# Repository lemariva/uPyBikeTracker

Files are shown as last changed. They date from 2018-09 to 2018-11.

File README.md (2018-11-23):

# uPyBikeTracker

## Main Hardware Components
| Part  | Description |  Qty |
|-:|-:|-:|
| [Wemos ESP32 Lora Board](https://www.banggood.com/2Pcs-Wemos-TTGO-LORA32-868915Mhz-ESP32-LoRa-OLED-0_96-Inch-Blue-Display-p-1239769.html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) | ESP32 + SSD1306 + SX1276 + CP2102| x1 |
| [GPS NEO7M](https://www.banggood.com/Ublox-NEO-7M-Flight-Controller-GPS-Module-Built-in-Data-Memory-p-973621.html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) / [GPS NEO6M](https://www.banggood.com/GY-NEO6MV2-New-NEO-6M-GPS-Module-NEO6MV2-with-Flight-Control-EEPROM-MWC-APM2_5-Large-Antenna-p-1348935.html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) | GPS Module| x1|
|[MPU9250/5](https://www.banggood.com/MPU-9250-GY-9250-9-Axis-Sensor-Module-I2C-SPI-Communication-Board-For-Arduino-p-1227241.html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)| IMU 10DOF Sensor| x1 |
|[IRLML2502](https://www.ebay.de/itm/20PCS-IRLML2502-ORIGINAL-MOSFET-N-CH-20V-4-2A-SOT-23-/162711066575) | MOSFETs | x4 | 
|[BME680](https://www.banggood.com/CJMCU-680-BME680-BOSCH-Temperature-And-Humidity-Pressure-Sensor-p-1268323.html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)| Atmospheric Pressure Sensor| x 1|
|[BQ27510-G3](http://www.ti.com/product/bq27510-g3/description) | Fuel Gauge |x1|
|[Lipo-Battery](https://www.banggood.com/ZOP-Power-3_7V-850mAh-1S-25C-Lipo-Battery-p-1013586.html?p=QW0903761303201409LG)| Battery| x1|
|[RTC Clock](https://www.conrad.de/de/ds1339u-33-tr-rtc-clockcalendar-i2c-interface-msop8-800202661.html)| Clock| x1 |
|[CR1220](https://www.conrad.de/de/knopfzellenhalter-1-cr-1216-cr-1220-horizontal-oberflaechenmontage-smd-l-x-b-x-h-1892-x-1207-x-318-mm-keystone-300-651317.html)| Battery Socket| x1 |
|[SIL Socket Row Strip PCB Connector](https://www.banggood.com/5-Pair-40-Pin-2_54mm-Male-Female-SIL-Socket-Row-Strip-PCB-Connector-p-953486.html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)| SIL Socket Row Strip PCB Connector | x1|
|[SMD Tact Push Buttons](https://www.banggood.com/100pcs-3-x-6-x-2_5mm-DC-12V-0_5A-SMD-Tact-Push-Button-Switch-p-1202259.html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)| Buttons| x4|
|[bq51013B](http://www.ti.com/product/BQ51013B/technicaldocuments)|  Highly Integrated Wireless Receiver Qi| x1|

## More Info
More info coming soon on [lemariva.com](https://lemariva.com).

## Revision
* 1.3v added wireless charging (not revised yet)
* 1.2v breakout boards integrated to the main board
* 1.1v added RTC Clock (DS1339)
* 1.0v initial commit

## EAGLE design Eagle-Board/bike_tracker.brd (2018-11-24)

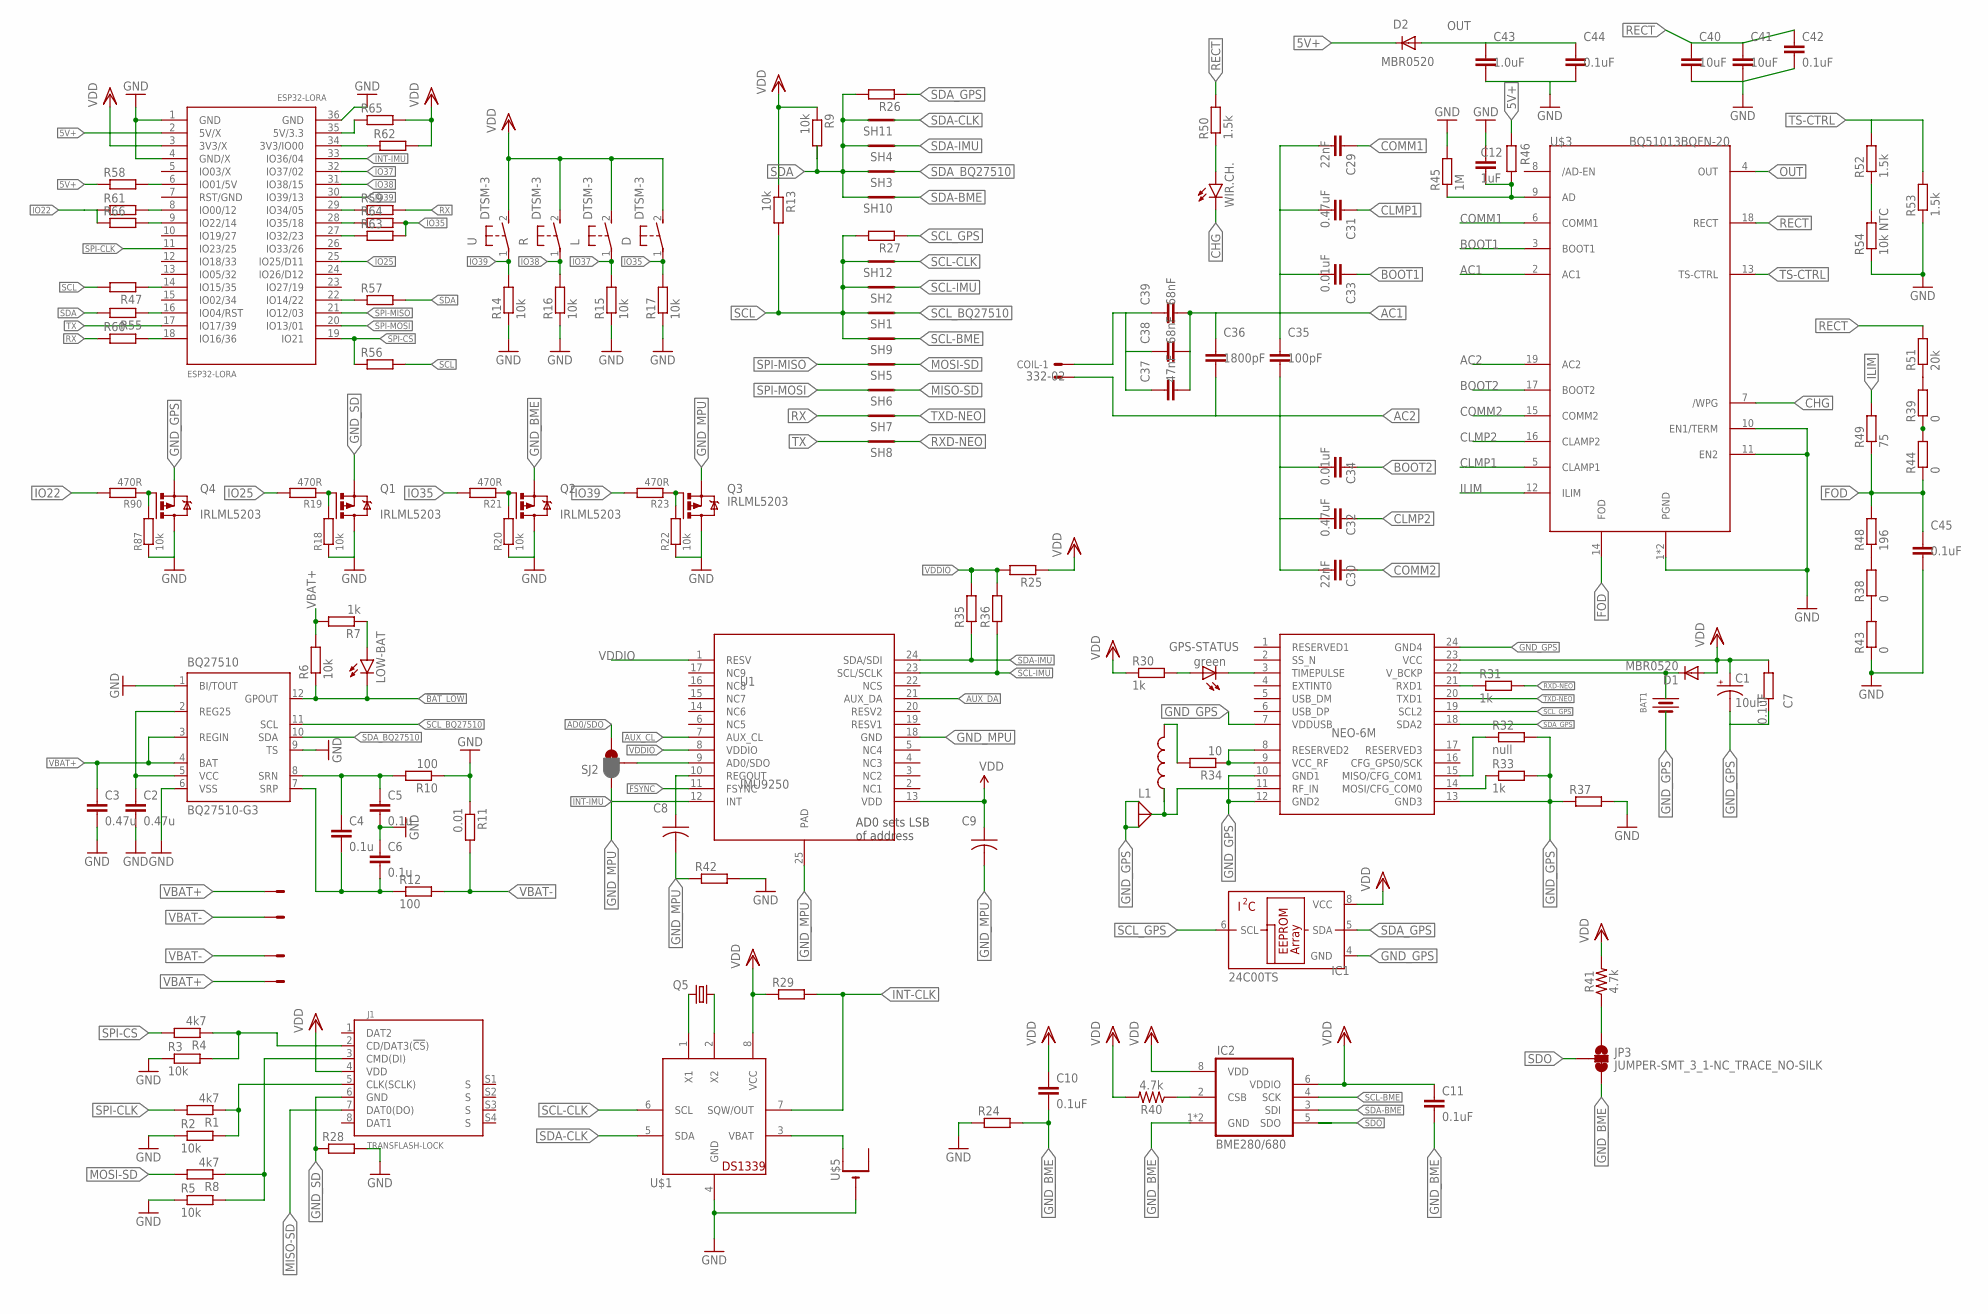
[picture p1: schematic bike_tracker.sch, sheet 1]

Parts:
BAT: 332-02
BAT1: XH414; TS414H
BAT-IN: 332-02
BQ27510: BQ27510-G3; DRZ
C1: 10uF; EIA3528
C2, C3: 0.47u; C0603
C4, C5, C6: 0.1u; C0603
C7: 0.1uF; R0603
C8, C9: 0.1uF; C0603K
C10, C11: 0.1uF; 0603
C12: 1uF; C0603
C29, C30: 22nF; C0603
C31, C32: 0.47uF; C0603
C33, C34: 0.01uF; C0603
C35: 100pF; C0603
C36: 1800pF; C0603
C37: 47nF; C0603
C38, C39: 68nF; C0603
C40, C41: 10uF; C0603
C42, C44, C45: 0.1uF; C0603
C43: 1.0uF; C0603
COIL: 332-02
D: DTSM-3
D1, D2: MBR0520; SOD123
ESP32-LORA: ESP32LORA; ESP32-LORA-TTGO
GPS-STATUS: green; 0805-LED
IC1: 24C00TS; TSSOP8
IC2: BME280/680; BME280
IPEX: ANT-UMCC; UMCC
J1: TRANSFLASH-LOCK; TRANSFLASH-LOCK-SOCK
JP3: JUMPER-SMT_3_1-NC_TRACE_NO-SILK; SMT-JUMPER_3_1-NC_TRACE_NO-SILK
L: DTSM-3
L1: INDUCTOR0603; 0603
LOW-BAT: LEDSML0805; SML0805
NEO-GPS: BLOX-NEO-6M; NE0-6M
Q1, Q2, Q3, Q4: IRLML5203; MICRO3
Q5: CRYSTALTC26H; TC26H
R: DTSM-3
R1, R4, R8: 4k7; R0603
R2, R3, R5, R6, R9, R13, R14, R15, R16, R17, R18, R20, R22, R87: 10k; R0603
R7, R30, R31, R33: 1k; R0603
R10, R12: 100; R0603
R11: 0.01; R0603
R19, R21, R23, R90: 470R; R0603
R24, R25, R26, R27, R28, R37, R42, R46, R47, R55, R56, R57, R58, R59, R60, R61, R62, R63, R64, R65, R66: R-EU_R0201; R0201
R29: R-EU_R0603; R0603
R32: null; R0603
R34: 10; R0603
R35, R36: 10K; R0603
R38, R39, R43, R44: 0; R0603
R40, R41: 4.7k; 0603
R45: 1M; R0603
R48: 196; R0603
R49: 75; R0603
R50, R52, R53: 1.5k; R0603
R51: 20k; R0603
R54: 10k NTC; R0603
SH1, SH2, SH3, SH4, SH5, SH6, SH7, SH8, SH9, SH10, SH11, SH12: SHORT; SHORT_TOP-20
SJ2: JUMPER_PAD-3-1&2_NC_BY_PASTE; PAD-HUMPER-3-1&2_NC_BY_PASTE_YES_SILK_FULL_BOX
U: DTSM-3
U1: IMU9250; LEAD-QFN24
U$1: DS1339; SOPM08
U$3: BQ51013BQFN-20; R-PVQFN-N20
U$5: CR1220SMT; CR1220-SMD
WIR.CH.: LEDSML0805; SML0805

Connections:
5V+: D2.C, ESP32-LORA.2 (5V/X), R46.2, R58.1
!BAT_LOW: BQ27510.12 (GPOUT), LOW-BAT.C, R6.1
AC1: C29.2, C31.1, C33.1, C35.1, C36.1, C37.2, C38.2, C39.2, U$3.2 (AC1)
AC1'1: C37.1, C38.1, C39.1, COIL.1
AC2: C30.1, C32.1, C34.1, C35.2, C36.2, COIL.2, U$3.19 (AC2)
AD0/SDO: SJ2.3
AUX_CL: U1.7 (AUX_CL)
AUX_DA: U1.21 (AUX_DA)
BOOT1: C33.2, U$3.3 (BOOT1)
BOOT2: C34.2, U$3.17 (BOOT2)
CHG: U$3.7 (/WPG), WIR.CH..C
CLMP1: C31.2, U$3.5 (CLAMP1)
CLMP2: C32.2, U$3.16 (CLAMP2)
COMM1: C29.1, U$3.6 (COMM1)
COMM2: C30.2, U$3.15 (COMM2)
FOD: C45.1, R44.1, R48.2, R49.1, U$3.14 (FOD)
FSYNC: U1.11 (FSYNC)
GND: BQ27510.1 (BI/TOUT), BQ27510.6 (VSS), BQ27510.9 (TS), C2.2, C3.2, C5.2, C6.1, C12.1, C40.2, C41.2, C42.2, C43.2, C44.2, C45.2, ESP32-LORA.1 (GND), ESP32-LORA.4 (GND/X), ESP32-LORA.36 (GND), Q1.3 (D), Q2.3 (D), Q3.3 (D), Q4.3 (D), R2.1, R3.1, R5.1, R10.1, R11.1, R14.1, R15.1, R16.1, R17.1, R18.1, R20.1, R22.1, R24.1, R28.2, R37.2, R42.2, R43.1, R45.2, R53.1, R54.1, R87.1, U$1.4 (GND), U$3.1 (PGND), U$3.10 (EN1/TERM), U$3.11 (EN2), U$3.20 (PGND), U$5.-
GND_BME: C10.2, C11.2, IC2.1 (GND), IC2.7 (GND), JP3.3, Q2.2 (S), R24.2
GND_GPS: BAT1.2 (-), C1.C (-), C7.2, IC1.4 (GND), IPEX.1 (GND1), IPEX.2 (GND2), NEO-GPS.7 (VDDUSB), NEO-GPS.10 (GND1), NEO-GPS.12 (GND2), NEO-GPS.13 (GND3), NEO-GPS.24 (GND4), Q4.2 (S), R32.2, R33.2, R37.1
GND_MPU: C8.2, C9.2, Q3.2 (S), R42.1, SJ2.1, U1.18 (GND), U1.25 (PAD)
GND_SD: J1.6 (GND), Q1.2 (S), R28.1
ILIM: R49.2, U$3.12 (ILIM)
INT-CLK: R29.2, U$1.7 (SQW/OUT)
INT-IMU: ESP32-LORA.33 (IO36/04), U1.12 (INT)
IO22: R61.1, R66.1, R90.2
IO25: ESP32-LORA.25 (IO25/D11), R19.2
IO35: D.1, R17.2, R21.2, R63.2, R64.2
IO37: ESP32-LORA.32 (IO37/02), L.1, R15.2
IO38: ESP32-LORA.31 (IO38/15), R.1, R16.2
IO39: ESP32-LORA.30 (IO39/13), R14.2, R23.2, U.1
MISO-SD: J1.7 (DAT0(DO)), SH6.1
MOSI-SD: R8.2, SH5.1
unnamed: J1.5 (CLK(SCLK)), R1.1, R2.2
unnamed: J1.2 (CD/DAT3(!CS!)), R3.2, R4.1
unnamed: J1.3 (CMD(DI)), R5.2, R8.1
unnamed: Q4.1 (G), R87.2, R90.1
unnamed: Q1.1 (G), R18.2, R19.1
unnamed: Q2.1 (G), R20.2, R21.1
unnamed: BQ27510.2 (REG25), BQ27510.5 (VCC), C2.1
unnamed: Q3.1 (G), R22.2, R23.1
unnamed: LOW-BAT.A, R7.1
unnamed: Q5.1, U$1.2 (X2)
unnamed: BQ27510.8 (SRN), C4.1, C5.1, R10.2
unnamed: ESP32-LORA.6 (IO01/5V), R58.2
unnamed: Q5.2, U$1.1 (X1)
unnamed: BQ27510.7 (SRP), C4.2, C6.2, R12.1
unnamed: U$1.3 (VBAT), U$5.+$1 (+)
unnamed: GPS-STATUS.A, R30.2
unnamed: GPS-STATUS.C, NEO-GPS.3 (TIMEPULSE)
unnamed: IPEX.3 (ANT), L1.1, NEO-GPS.11 (RF_IN)
unnamed: NEO-GPS.21 (RXD1), R31.1
unnamed: NEO-GPS.15 (MISO/CFG_COM1), R32.1
unnamed: NEO-GPS.14 (MOSI/CFG_COM0), R33.1
unnamed: BAT1.1 (+), D1.C, NEO-GPS.22 (V_BCKP)
unnamed: L1.2, R34.2
unnamed: NEO-GPS.8 (RESERVED2), NEO-GPS.9 (VCC_RF), R34.1
unnamed: IC2.2 (CSB), R40.1
unnamed: JP3.1, R41.1
unnamed: SJ2.2, U1.9 (AD0/SDO)
unnamed: R38.2, R48.1
unnamed: R39.2, R51.1
unnamed: R50.1, WIR.CH..A
unnamed: R52.1, R54.2
unnamed: C12.2, R45.1, R46.1, U$3.9 (AD)
unnamed: R38.1, R43.2
unnamed: R39.1, R44.2
unnamed: ESP32-LORA.14 (IO15/35), R47.1
unnamed: ESP32-LORA.16 (IO04/RST), R55.1
unnamed: ESP32-LORA.22 (IO14/22), R57.1
unnamed: ESP32-LORA.29 (IO34/05), R59.1
unnamed: ESP32-LORA.18 (IO16/36), R60.2
unnamed: ESP32-LORA.34 (3V3/IO00), R62.1
unnamed: ESP32-LORA.8 (IO00/12), R61.2
unnamed: ESP32-LORA.35 (5V/3.3), R65.1
unnamed: ESP32-LORA.28 (IO35/18), R64.1
unnamed: ESP32-LORA.9 (IO22/14), R66.2
unnamed: ESP32-LORA.27 (IO32/23), R63.1
OUT: C43.1, C44.1, D2.A, U$3.4 (OUT)
PWPD: BQ27510.EXP@1 (PWPD), BQ27510.EXP@2 (PWPD), BQ27510.EXP@3 (PWPD), BQ27510.EXP@4 (PWPD), BQ27510.EXP@5 (PWPD), BQ27510.EXP@6 (PWPD), BQ27510.EXP@7 (PWPD), BQ27510.EXP@8 (PWPD), BQ27510.EXP@9 (PWPD)
RECT: C40.1, C41.1, C42.1, R50.2, R51.2, U$3.18 (RECT)
REGOUT: C8.1, U1.10 (REGOUT)
RX: R59.2, R60.1, SH7.2
RXD-NEO: R31.2, SH8.1
SCL: R13.2, R27.2, R47.2, R56.2, SH1.2, SH2.2, SH9.2, SH12.2
SCL-BME: IC2.4 (SCK), SH9.1
SCL-CLK: SH12.1, U$1.6 (SCL)
SCL-IMU: R36.1, SH2.1, U1.23 (SCL/SCLK)
SCL_BQ27510: BQ27510.11 (SCL), SH1.1
SCL_GPS: IC1.6 (SCL), NEO-GPS.19 (SCL2), R27.1
SDA: R9.2, R26.2, R55.2, R57.2, SH3.2, SH4.2, SH10.2, SH11.2
SDA-BME: IC2.3 (SDI), SH10.1
SDA-CLK: SH11.1, U$1.5 (SDA)
SDA-IMU: R35.1, SH4.1, U1.24 (SDA/SDI)
SDA_BQ27510: BQ27510.10 (SDA), SH3.1
SDA_GPS: IC1.5 (SDA), NEO-GPS.18 (SDA2), R26.1
SDO: IC2.5 (SDO), JP3.2
SPI-CLK: ESP32-LORA.11 (IO23/25), R1.2
SPI-CS: ESP32-LORA.19 (IO21), R4.2, R56.1
SPI-MISO: ESP32-LORA.21 (IO12/03), SH5.2
SPI-MOSI: ESP32-LORA.20 (IO13/01), SH6.2
TS-CTRL: R52.2, R53.2, U$3.13 (TS-CTRL)
TX: ESP32-LORA.17 (IO17/39), SH8.2
TXD-NEO: NEO-GPS.20 (TXD1), SH7.1
VBAT+: BAT.1, BAT-IN.1, BQ27510.3 (REGIN), BQ27510.4 (BAT), C3.1, R6.2, R7.2
VBAT-: BAT.2, BAT-IN.2, R11.2, R12.2
VDD: C1.A (+), C7.1, C9.1, C10.1, C11.1, D.2, D1.A, ESP32-LORA.3 (3V3/X), IC1.8 (VCC), IC2.6 (VDDIO), IC2.8 (VDD), J1.4 (VDD), L.2, NEO-GPS.23 (VCC), R.2, R9.1, R13.1, R25.1, R29.1, R30.1, R40.2, R41.2, R62.2, R65.2, U.2, U1.13 (VDD), U$1.8 (VCC)
VDDIO: R25.2, R35.2, R36.2, U1.1 (RESV), U1.8 (VDDIO)

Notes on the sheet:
AD0 sets LSB of address

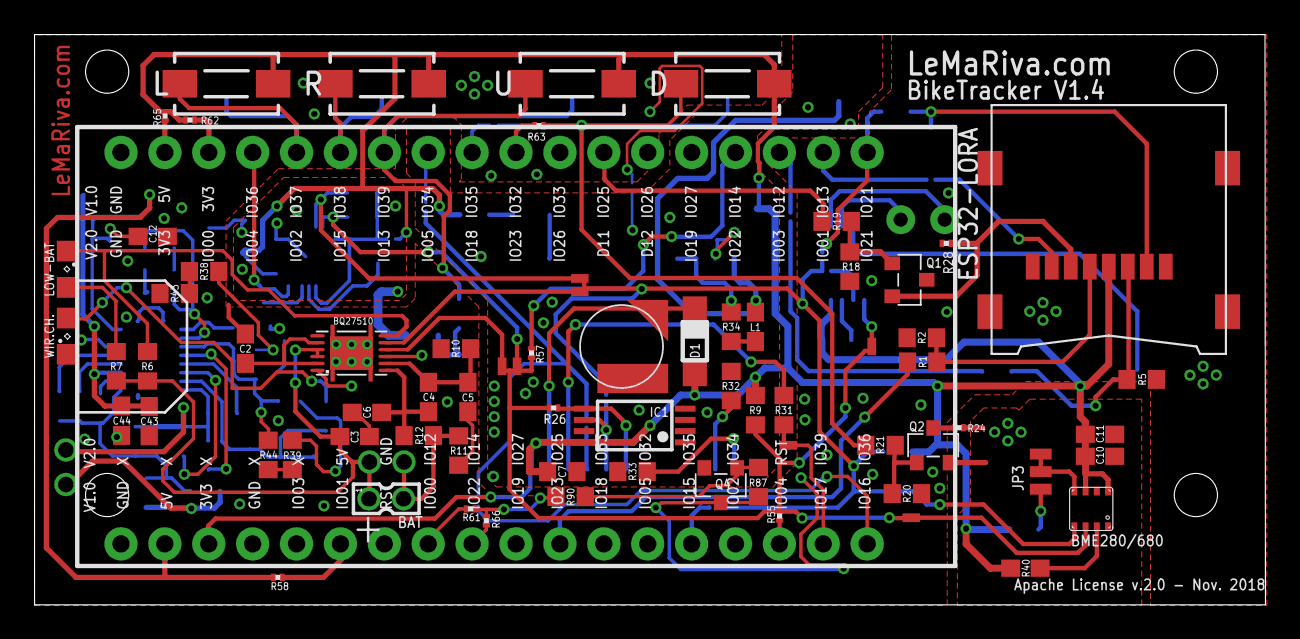
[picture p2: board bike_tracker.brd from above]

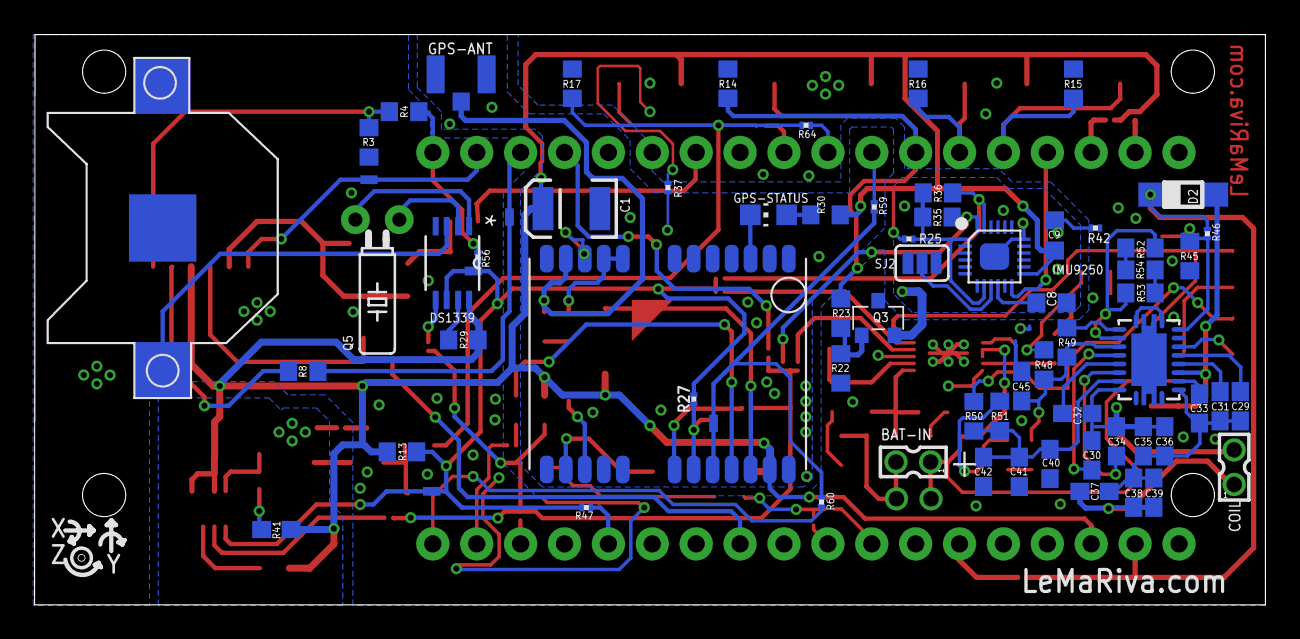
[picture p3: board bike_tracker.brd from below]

Board: 2 copper layers, 71.2 x 33.0 mm, 141 parts (69 on the bottom side), 104 nets.

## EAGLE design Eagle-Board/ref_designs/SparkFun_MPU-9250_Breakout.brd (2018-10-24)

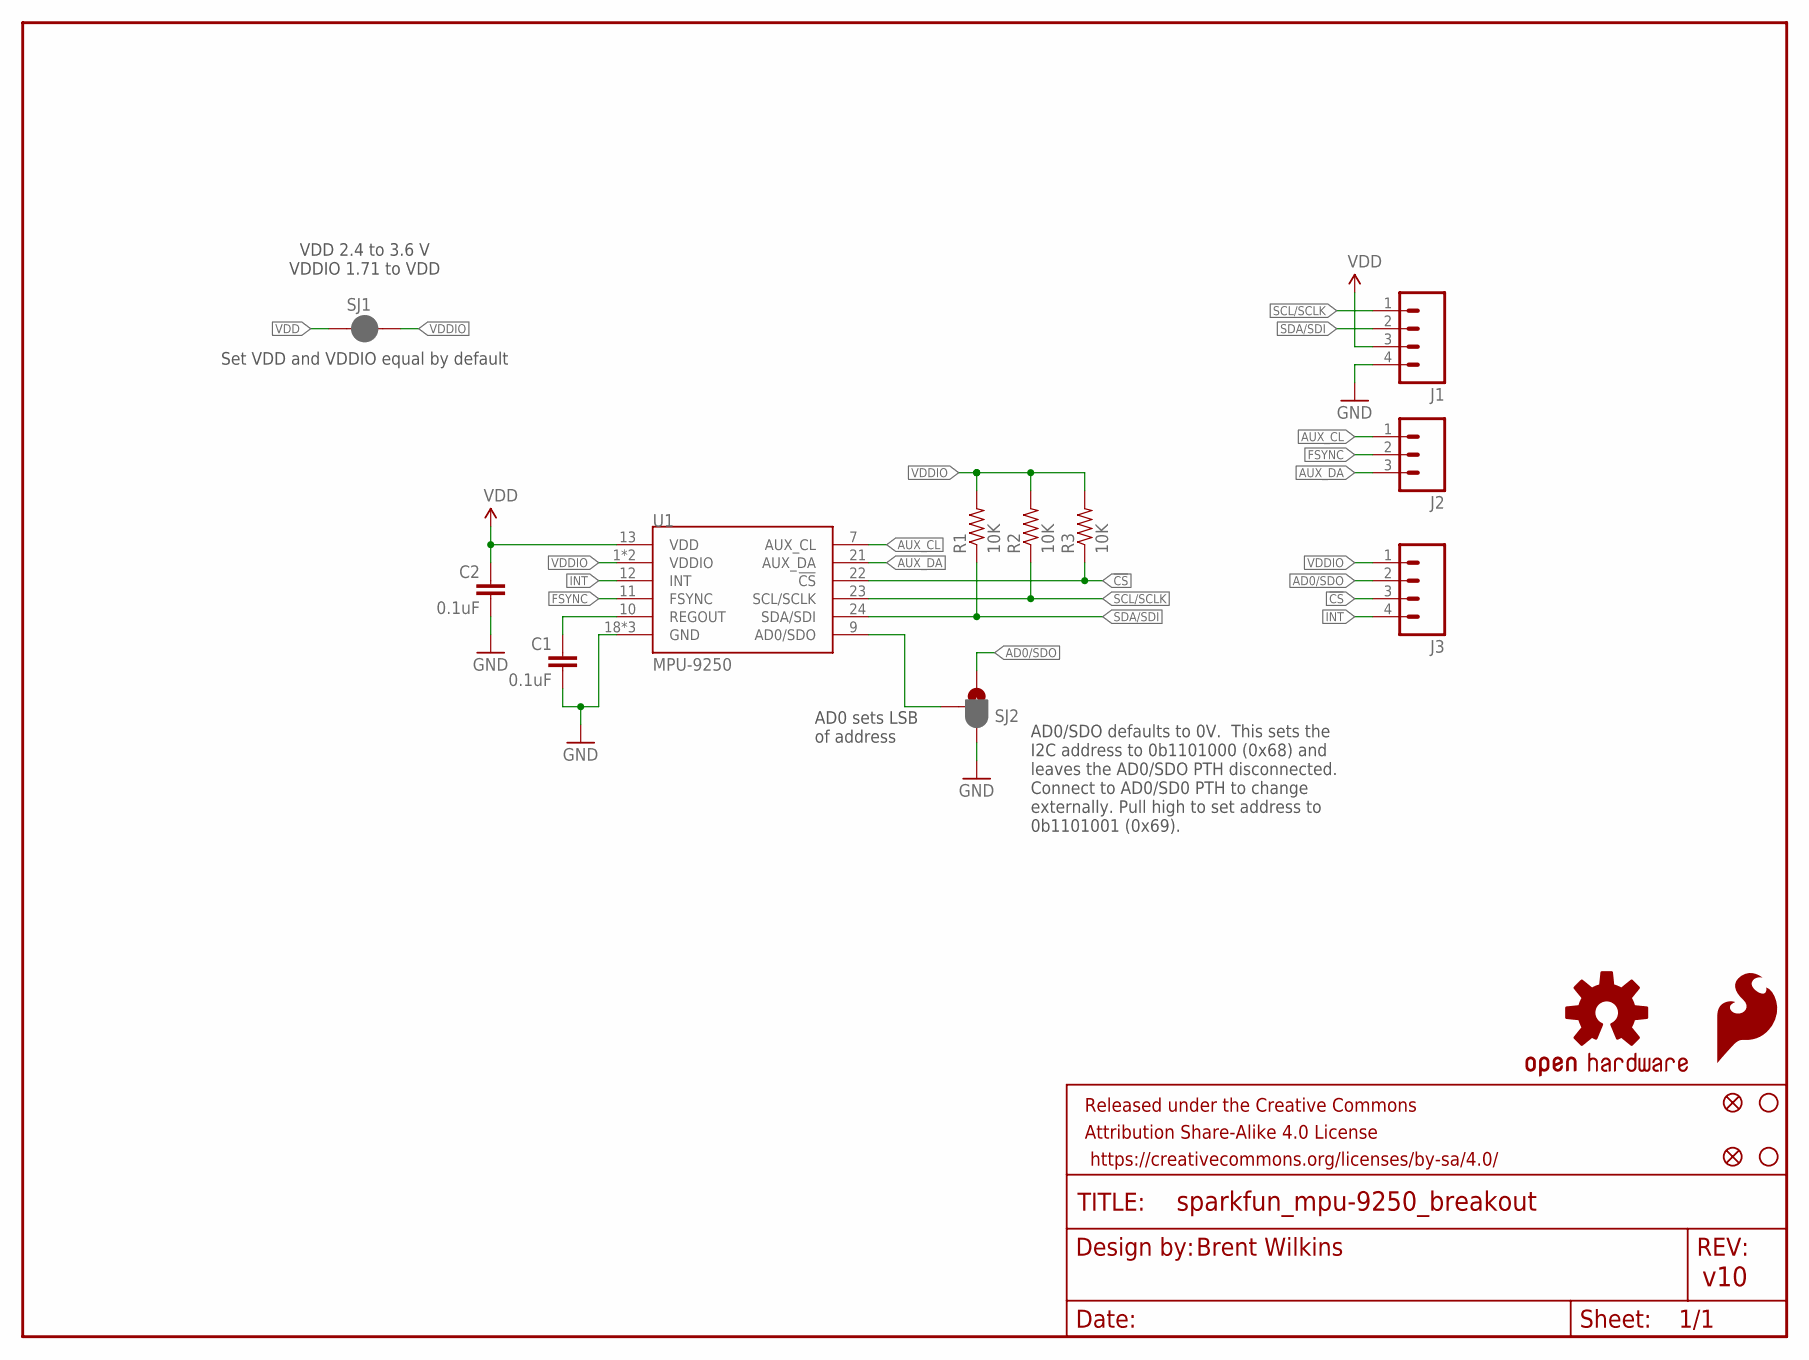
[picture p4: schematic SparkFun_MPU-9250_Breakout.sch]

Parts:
C1, C2: 0.1uF; 0603-CAP
FID1, FID2: FIDUCIAL1X2; FIDUCIAL-1X2
FRAME1: FRAME-LETTER; CREATIVE_COMMONS
J1, J3: M04PTH; 1X04
J2: M03PTH; 1X03
LOGO1: SFE_LOGO_FLAME.1_INCH; SFE_LOGO_FLAME_.1
LOGO2: OSHW-LOGOS; OSHW-LOGO-S
R1, R2, R3: 10K; 0603-RES
SJ1: JUMPER-PAD-2-NC_BY_PASTEFULL-BOX-SILK; PAD-JUMPER-2-NC_BY_PASTE_YES_SILK_FULL_BOX
SJ2: JUMPER_PAD-3-1&2_NC_BY_PASTE; PAD-HUMPER-3-1&2_NC_BY_PASTE_YES_SILK_FULL_BOX
STANDOFF1, STANDOFF2: STAND-OFF
U1: MPU-9250; QFN24_PAD

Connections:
!CS: J3.3, R3.1, U1.22 (!CS)
AD0/SDO: J3.2, SJ2.3
ADSD_STUB: SJ2.2, U1.9 (AD0/SDO)
AUX_CL: J2.1, U1.7 (AUX_CL)
AUX_DA: J2.3, U1.21 (AUX_DA)
FSYNC: J2.2, U1.11 (FSYNC)
GND: C1.2, C2.2, J1.4, SJ2.1, U1.18 (GND), U1.20 (GND), U1.CENTER (GND)
INT: J3.4, U1.12 (INT)
REGOUT: C1.1, U1.10 (REGOUT)
SCL/SCLK: J1.1, R2.1, U1.23 (SCL/SCLK)
SDA/SDI: J1.2, R1.1, U1.24 (SDA/SDI)
VDD: C2.1, J1.3, SJ1.1, U1.13 (VDD)
VDDIO: J3.1, R1.2, R2.2, R3.2, SJ1.2, U1.1 (VDDIO), U1.8 (VDDIO)

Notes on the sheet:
AD0/SDO defaults to 0V. This sets the I2C address to 0b1101000 (0x68) and leaves the AD0/SDO PTH disconnected. Connect to AD0/SD0 PTH to change externally. Pull high to set address to 0b1101001 (0x69).
AD0 sets LSB of address
Set VDD and VDDIO equal by default
VDD 2.4 to 3.6 V VDDIO 1.71 to VDD

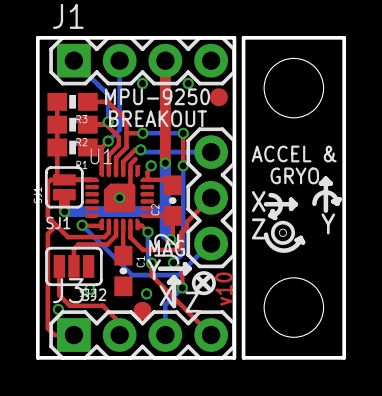
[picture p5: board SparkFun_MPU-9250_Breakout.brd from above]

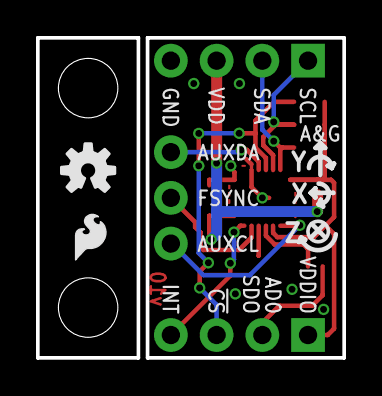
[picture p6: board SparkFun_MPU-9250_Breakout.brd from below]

Board: 2 copper layers, 17.0 x 17.8 mm, 18 parts (2 on the bottom side), 13 nets.

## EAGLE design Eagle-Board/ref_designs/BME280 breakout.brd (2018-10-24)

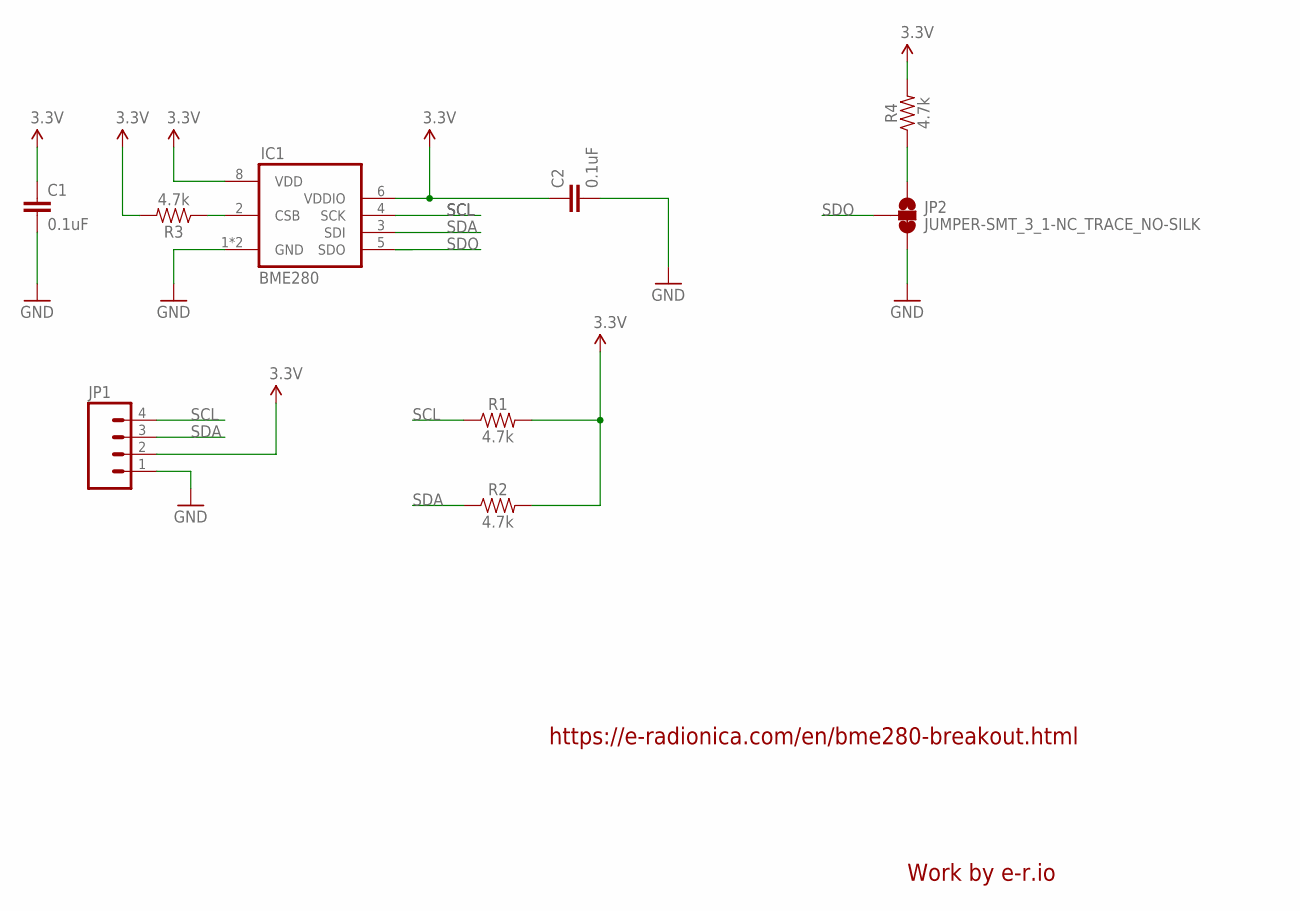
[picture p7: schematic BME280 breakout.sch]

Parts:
C1, C2: 0.1uF; 0603
IC1: BME280
JP1: M04PTH; 1X04
JP2: JUMPER-SMT_3_1-NC_TRACE_NO-SILK; SMT-JUMPER_3_1-NC_TRACE_NO-SILK
R1, R2, R3, R4: 4.7k; 0603

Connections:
3.3V: C1.1, C2.1, IC1.6 (VDDIO), IC1.8 (VDD), JP1.2, R1.2, R2.2, R3.2, R4.2
GND: C1.2, C2.2, IC1.1 (GND), IC1.7 (GND), JP1.1, JP2.3
unnamed: IC1.2 (CSB), R3.1
unnamed: JP2.1, R4.1
SCL: IC1.4 (SCK), JP1.4, R1.1
SDA: IC1.3 (SDI), JP1.3, R2.1
SDO: IC1.5 (SDO), JP2.2

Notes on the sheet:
https://e-radionica.com/en/bme280-breakout.html
Work by e-r.io

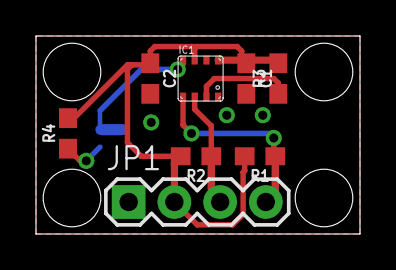
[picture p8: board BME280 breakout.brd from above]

Board: 2 copper layers, 18.0 x 11.0 mm, 11 parts (1 on the bottom side), 7 nets.

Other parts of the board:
U$1: OSH3MM
U$2: NOVI_LOGO-4MM

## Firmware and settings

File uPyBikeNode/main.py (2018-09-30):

#import LoRaDuplexCallback
#import LoRaPingPong
#import LoRaSender
#import LoRaReceiver
import gc, os
import _thread
from machine import SPI, UART, Pin
import network
from time import sleep
import config_lora
from sx127x import SX127x
from controller_esp32 import ESP32Controller
from uPySensors.mpu9250 import MPU9250
from uPySensors.ssd1306_i2c import Display
from uPySensors.ublox_gps import MicropyGPS
from uPySensors.sdcard import SDCard

# settings
_booting = 0
_sleeping = 1
_moving  = 2

settings = {}
settings['irq'] = 0
settings['status'] = _booting

def collect_garbage():
    gc.collect()
    print('[Memory - free: {}   allocated: {}]'.format(gc.mem_free(), gc.mem_alloc()))

# pretty networks
def netpretty(network):
    net = {'name': network[0], 'bssid': str(prettify(network[1])), 'rssi': network[3], 'channel': network[2]}
    return net

# prettify mac address
def prettify(mac_binary):
    return ':'.join('%02x' % (b) for b in mac_binary)

# imu handler
moving_text = '.......'
moving_limit = 6
def mpu_irq_handler(handler):
    global settings
    settings['irq'] = settings['irq'] + 1
    if(settings['irq'] > moving_limit):
        settings['status'] = 2
        #display.poweron()
        display.show_text_wrap("Booting...")
        sensor.disable_irq_mode()
    else:
        display.show_text_wrap(moving_text[0:settings['irq']])

# communication
msgCount = 0                           # count of outgoing messages
intervalUpdates = [  1000,       # imu
                    10000,       # gps
                    20000,       # wlan
                     1000,       # display
                     5000,       # save data
                    10000]       # send data lora

controller = ESP32Controller()
lora = controller.add_transceiver(SX127x(name = 'LoRa'),
                                  pin_id_ss = ESP32Controller.PIN_ID_FOR_LORA_SS,
                                  pin_id_RxDone = ESP32Controller.PIN_ID_FOR_LORA_DIO0)
def gen_message(NODE_NAME, message, millisecond):
    return "{} {} {}".format(NODE_NAME, message, millisecond)

def on_receive(lora, payload):
    print('lora handler')

lora.onReceive(on_receive)

# imu settings
sensor = MPU9250(-1)
sensor.accel_range = 0
sensor.gyro_range = 1
sensor.filter_range = 1
irq_pin = Pin(25, mode=Pin.IN)
irq_pin.irq(trigger=Pin.IRQ_RISING, handler=mpu_irq_handler)

# display
display = Display()

# sd cards
spi_sd = SPI(1, sck = Pin(23, Pin.OUT), mosi = Pin(13, Pin.OUT), miso = Pin(12, Pin.IN))
sd = SDCard(spi_sd, Pin(21))
os.mount(sd, '/sd')

# gps
uart = UART(1, rx=34, tx=17)            # init with given baudrate
uart.init(9600, bits=8, parity=None, stop=1)    # init with given parameters
my_gps = MicropyGPS()

# wlan
station = network.WLAN(network.STA_IF)

if (settings['status'] == _booting):
    sensor.enable_irq_mode()
    #machine.freq(80000000)
    #machine.idle()
    settings['status'] = _sleeping


lastUpdateTimes = [0, 0, 0, 0, 0, 0]
NODE_NAME = config_lora.get_nodename()

data = {'nodes': [],
        'imu': [],
        'satellites': 0,
        'gps': [],
        'speed': "",
        'time': []}

def update_data():
    global config_lora, station, my_gps, sensor, data, intervalUpdates, lastUpdateTimes
    now = config_lora.get_millis()

    if now < lastUpdateTimes[0]: lastUpdateTimes[0] = now

    if (now - lastUpdateTimes[0] > intervalUpdates[0]):
        lastUpdateTimes[0] = now
        print('imu')
        data['imu'] = [sensor.accel, sensor.gyro, sensor.mag, sensor.temperature]
        collect_garbage()

    if (now - lastUpdateTimes[1] > intervalUpdates[1]):
        lastUpdateTimes[1] = now
        print('gps')
        stat = my_gps.updateall(uart.read(), True)
        data['satellites'] = my_gps.satellites_in_use
        data['gps'] = (my_gps.latitude_decimal(), my_gps.longitude_decimal(), my_gps.altitude) + my_gps.speed
        data['speed'] = my_gps.speed_string()
        data['time'] = my_gps.timestamp
        collect_garbage()

    if (now - lastUpdateTimes[2] > intervalUpdates[2]):
        lastUpdateTimes[2] = now
        print('wlan')
        # wlan
        if(not station.active()):
            station.active(True)

        networks = station.scan()
        wlan_nodes = []
        for net in networks:
            wlan_node = netpretty(net)
            wlan_nodes.append(wlan_node)

        data['nodes'] = wlan_nodes
        collect_garbage()

def update_display():
    global config_lora, display, data, intervalUpdates, lastUpdateTimes
    now = config_lora.get_millis()
    if now < lastUpdateTimes[3]: lastUpdateTimes[3] = now
    if (now - lastUpdateTimes[3] > intervalUpdates[3]):
        lastUpdateTimes[3] = now
        print('display')
        try:
            gps = data['gps']
            accel = data['imu'][0]
            # display information
            display.show_text('Lat.:{:04.2f}'.format(gps[0]), 0, 0, True)
            display.show_text('Long.:{:04.2f}'.format(gps[1]), 0, 10, False)
            display.show_text('Speed:{}'.format(data['speed']), 0, 20, False)
            display.show_text('A:({:03.1f},{:03.1f},{:03.1f})'.format(accel.x, accel.y, accel.z), 0, 30, False)
            display.show_text('WF:{0}|LoRa:{1}'.format(len(data['nodes']), lora.packetRssi()), 0, 40, False)
            display.show_text('Time:{:02d}:{:02d}:{:02.1f}'.format(data['time'][0],data['time'][1],data['time'][2]), 0, 50, False)
            collect_garbage()
        except:
            display.show_text('Waiting for data...', 0, 0, True)

def save_data():
    global data

    if now < lastUpdateTimes[4]: lastUpdateTimes[4] = now
    if (now - lastUpdateTimes[4] > intervalUpdates[4]):
        lastUpdateTimes[4] = now
        print('save')
        try:
            save_time = ','.join([str(x) for x in data['time']])
            save_gps  = ','.join([str(x) for x in data['gps']])
            save_imu  = data['imu'][0].xyz + data['imu'][1].xyz + data['imu'][2].xyz
            save_imu  = ','.join([str(x) for x in save_imu]) + ',' + str(data['imu'][3])
            #for net in data['nodes']:
                ### TODO: save wlan data


            fn = '/sd/data.txt'
            with open(fn,'a') as f:
                n = f.write(save_time + ',' + save_gps + ',' + save_imu + '\n') # one block
                print(n, 'bytes written')
        except:
            print('Error writing data!')

        collect_garbage()


def send_data():
    global config_lora, lora, data, intervalUpdates, lastUpdateTimes
    now = config_lora.get_millis()
    if now < lastUpdateTimes[5]: lastUpdateTimes[5] = now
    if (now - lastUpdateTimes[5] > intervalUpdates[5]):
        lastUpdateTimes[5] = now                            # timestamp the message
        print('lora')
        try:
            save_time = ','.join([str(x) for x in data['time']])
            save_gps  = ','.join([str(x) for x in data['gps']])
            save_imu  = data['imu'][0].xyz + data['imu'][1].xyz + data['imu'][2].xyz
            save_imu  = ','.join([str(x) for x in save_imu]) + ',' + str(data['imu'][3])

            msg = save_time + ',' + save_gps + ',' + save_imu
            # lora message generation
            print(msg)

            message = gen_message(NODE_NAME, msg, now)
            lora.println(msg)                                   # send message
            lora.receive()                                          # go back into receive mode
        except:
            print('Error sending data')

        collect_garbage()

while True:
    now = config_lora.get_millis()

    if(settings['status'] == _sleeping):
        station.active(False)
        #display.poweroff()

    elif(settings['status'] == _moving):
        update_display()
        update_data()
        save_data()
        send_data()

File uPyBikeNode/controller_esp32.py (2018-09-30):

from machine import Pin, SPI, reset
from controller import Controller

class ESP32Controller(Controller):

    # LoRa config
    PIN_ID_FOR_LORA_RESET = 14

    PIN_ID_FOR_LORA_SS = 18
    PIN_ID_SCK = 5
    PIN_ID_MOSI = 27
    PIN_ID_MISO = 19

    PIN_ID_FOR_LORA_DIO0 = 5
    PIN_ID_FOR_LORA_DIO1 = None
    PIN_ID_FOR_LORA_DIO2 = None
    PIN_ID_FOR_LORA_DIO3 = None
    PIN_ID_FOR_LORA_DIO4 = None
    PIN_ID_FOR_LORA_DIO5 = None


    # ESP config
    ON_BOARD_LED_PIN_NO = 2
    ON_BOARD_LED_HIGH_IS_ON = True
    GPIO_PINS = (0, 1, 2, 3, 4, 5, 6, 7, 8, 9, 10, 11,
                 12, 13, 14, 15, 16, 17, 18, 19, 21, 22,
                 23, 25, 26, 27, 32, 34, 35, 36, 37, 38, 39)


    def __init__(self,
                 pin_id_led = ON_BOARD_LED_PIN_NO,
                 on_board_led_high_is_on = ON_BOARD_LED_HIGH_IS_ON,
                 pin_id_reset = PIN_ID_FOR_LORA_RESET,
                 blink_on_start = (2, 0.5, 0.5)):

        super().__init__(pin_id_led,
                         on_board_led_high_is_on,
                         pin_id_reset,
                         blink_on_start)


    def prepare_pin(self, pin_id, in_out = Pin.OUT):
        if pin_id is not None:
            pin = Pin(pin_id, in_out)
            new_pin = Controller.Mock()
            new_pin.pin_id = pin_id
            new_pin.value = pin.value

            if in_out == Pin.OUT:
                new_pin.low = lambda : pin.value(0)
                new_pin.high = lambda : pin.value(1)
            else:
                new_pin.irq = pin.irq

            return new_pin


    def prepare_irq_pin(self, pin_id):
        pin = self.prepare_pin(pin_id, Pin.IN)
        if pin:
            pin.set_handler_for_irq_on_rising_edge = lambda handler: pin.irq(handler = handler, trigger = Pin.IRQ_RISING)
            pin.detach_irq = lambda : pin.irq(handler = None, trigger = 0)
            return pin


    def get_spi(self):
        spi = None

        try:
            spi = SPI(baudrate = 10000000, polarity = 0, phase = 0, bits = 8, firstbit = SPI.MSB,
                      sck = Pin(self.PIN_ID_SCK, Pin.OUT, Pin.PULL_DOWN),
                      mosi = Pin(self.PIN_ID_MOSI, Pin.OUT, Pin.PULL_UP),
                      miso = Pin(self.PIN_ID_MISO, Pin.IN, Pin.PULL_UP))
            #spi.init()

        except Exception as e:
            print(e)
            if spi:
                spi.deinit()
                spi = None
            reset()  # in case SPI is already in use, need to reset.

        return spi


    def prepare_spi(self, spi):

        if spi:
            new_spi = Controller.Mock()

            def transfer(pin_ss, address, value = 0x00):
                response = bytearray(1)

                pin_ss.low()

                spi.write(bytes([address]))
                spi.write_readinto(bytes([value]), response)

                pin_ss.high()

                return response

            new_spi.transfer = transfer
            new_spi.close = spi.deinit
            return new_spi


    def __exit__(self):
        self.spi.close()

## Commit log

2018-10-01 added eagle board for bike tracker - work in progress
    [bike_tracker.brd, bike_tracker.sch]
2018-10-01 board design ready - revising and exporting for gerber - SeeedStudio Fusion files added
    [bike_tracker.brd, bike_tracker.sch]
2018-10-01 texas and switch libraries added final version with buttons and possibility to switch off/on external devices
    [bike_tracker.brd, bike_tracker.sch]
2018-10-01 minor modifications made
    [bike_tracker.brd]
2018-10-20 updated rev1.1 -> added RTC chip (DS1339)
    [bike_tracker.brd, bike_tracker.sch]
2018-10-24 revision v1.2
    [BME280 breakout.brd, BME280 breakout.sch, Microduino-NEO6M.sch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]
2018-10-24 first commit rev1.2
    [bike_tracker.brd, bike_tracker.sch]
2018-10-24 minor modifications
    [bike_tracker.brd]
2018-10-26 modified and cleaned for production
    [bike_tracker.brd, bike_tracker.sch]
2018-10-26 last minute modifications added
    [bike_tracker.brd, bike_tracker.sch]
2018-11-23 wireless charging option added
    [bike_tracker.brd, bike_tracker.sch]
2018-11-24 added compatibility with TTGO LoRa v2.0
    [bike_tracker.brd, bike_tracker.sch]
2018-11-24 minor error correction and exported for production!
    [bike_tracker.brd, bike_tracker.sch]

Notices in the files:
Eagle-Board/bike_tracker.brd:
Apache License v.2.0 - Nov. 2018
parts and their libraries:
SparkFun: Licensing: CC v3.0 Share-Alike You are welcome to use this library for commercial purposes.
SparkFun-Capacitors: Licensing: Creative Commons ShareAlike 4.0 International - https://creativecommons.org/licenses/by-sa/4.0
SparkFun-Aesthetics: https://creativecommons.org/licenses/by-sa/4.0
